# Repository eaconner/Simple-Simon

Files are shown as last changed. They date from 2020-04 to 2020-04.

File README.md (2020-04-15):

# Simple Simon Kit #

Simple Simon

Red then green...no, blue?...wait!...BUZZ! Remember the classic game of Simon?
Well, here is a build-your-own Simon kit that will sharpen your reaction time while teaching you basic soldering (a useful skill in its own right).

After you have successfully built a working Simon game, you will have a greater knowledge of through-hole soldering and the tools, techniques, and terminology required to populate your own PCB prototype. Additionally, the source code and design files are available, making this project a great entryway into microcontrollers and embedded programming. Game on!

## Parts List ##
|	Qty	|	Part				|	Description				|	Digikey Part #	|
|:-----:|---|---|---|
|	1	|	U1					|	Atmel ATtiny45			|	ATTINY45-20PU	|
|	4	|	R1, R2, R3, R4		|	470ohm 1/4w Resistor	|	CF14JT470RCT	|
|	1	|	D1					|	5mm Red LED				|	160-1678		|
|	1	|	D2					|	5mm Green LED			|	160-1677		|
|	1	|	D3					|	5mm Blue LED			|	160-1610		|
|	1	|	D4					|	5mm Yellow LED			|	160-1686		|
|	1	|	SG1					|	12mm Piezo Buzzer		|	102-3752		|
|	5	|	S1, S2, S3, S4, S5	|	Pushbutton				|	450-1644		|
|	1	|	BAT1				|	Battery Holder			|	BS-7			|
|	1	|	BAT1				|	CR2032 Battery			|	P189			|

## Instructions ##
1. Insert the ATtiny45 microcontroller into U1. Make sure the dot in the corner of the chip is aligned with the white silk screen dot on the board. Flip the board over, then solder into place.
2. Insert the (4) four resistors into R1, R2, R3, & R4 by bending the legs down. Flip the board over and solder into place.
3. Insert the (4) four LEDs into D1, D2, D3, & D4. Each LED has a short leg and a long leg. The long leg goes into the hole closest to the edge of the board. Also make sure it sits flush with the PCB. Then solder into place. **Note: You can check the color of the LED by touching the long leg to the "+" side of the CR2032 battery and the short leg to the "-" side.**
4. Insert the buzzer into SG1. Flip the board over and solder into place.
5. Insert the battery holder on the back of the board into BAT1. Flip the board over and solder into place.
6. Insert the battery into the holder.

## Gameplay ##

Press the "Start" button to begin. Memorize and repeat an increasing sequence of colors and tones. In higher levels the game goes faster. If you make a mistake, the correct LED blinks three times and game-over animation is played. If you have beaten the best score, your score is saved and the best-score animation is played.

- If the **red** button is held during when the start button is pressed, the best score is erased.
- If the **green** button is held during when the start button is pressed, starts a random sequence of lights and tones.
- If the **blue** button is held during when the start button is pressed, starts a new game at the highest achieved level.
- If the **yellow** button is held during when the start button is pressed, toggles the sound on or off.

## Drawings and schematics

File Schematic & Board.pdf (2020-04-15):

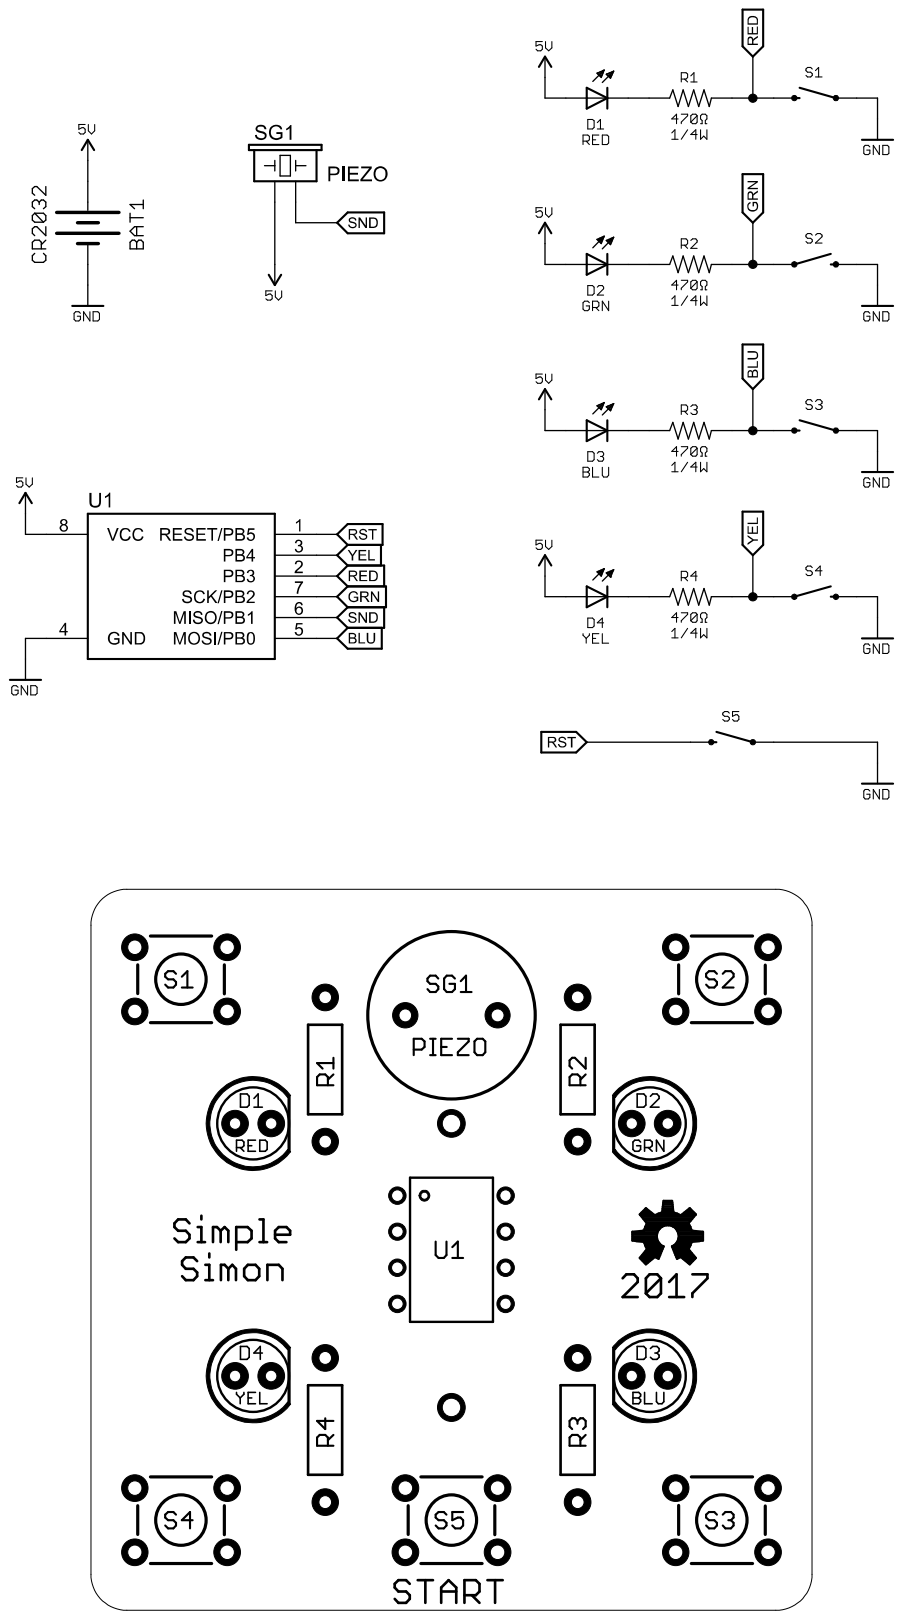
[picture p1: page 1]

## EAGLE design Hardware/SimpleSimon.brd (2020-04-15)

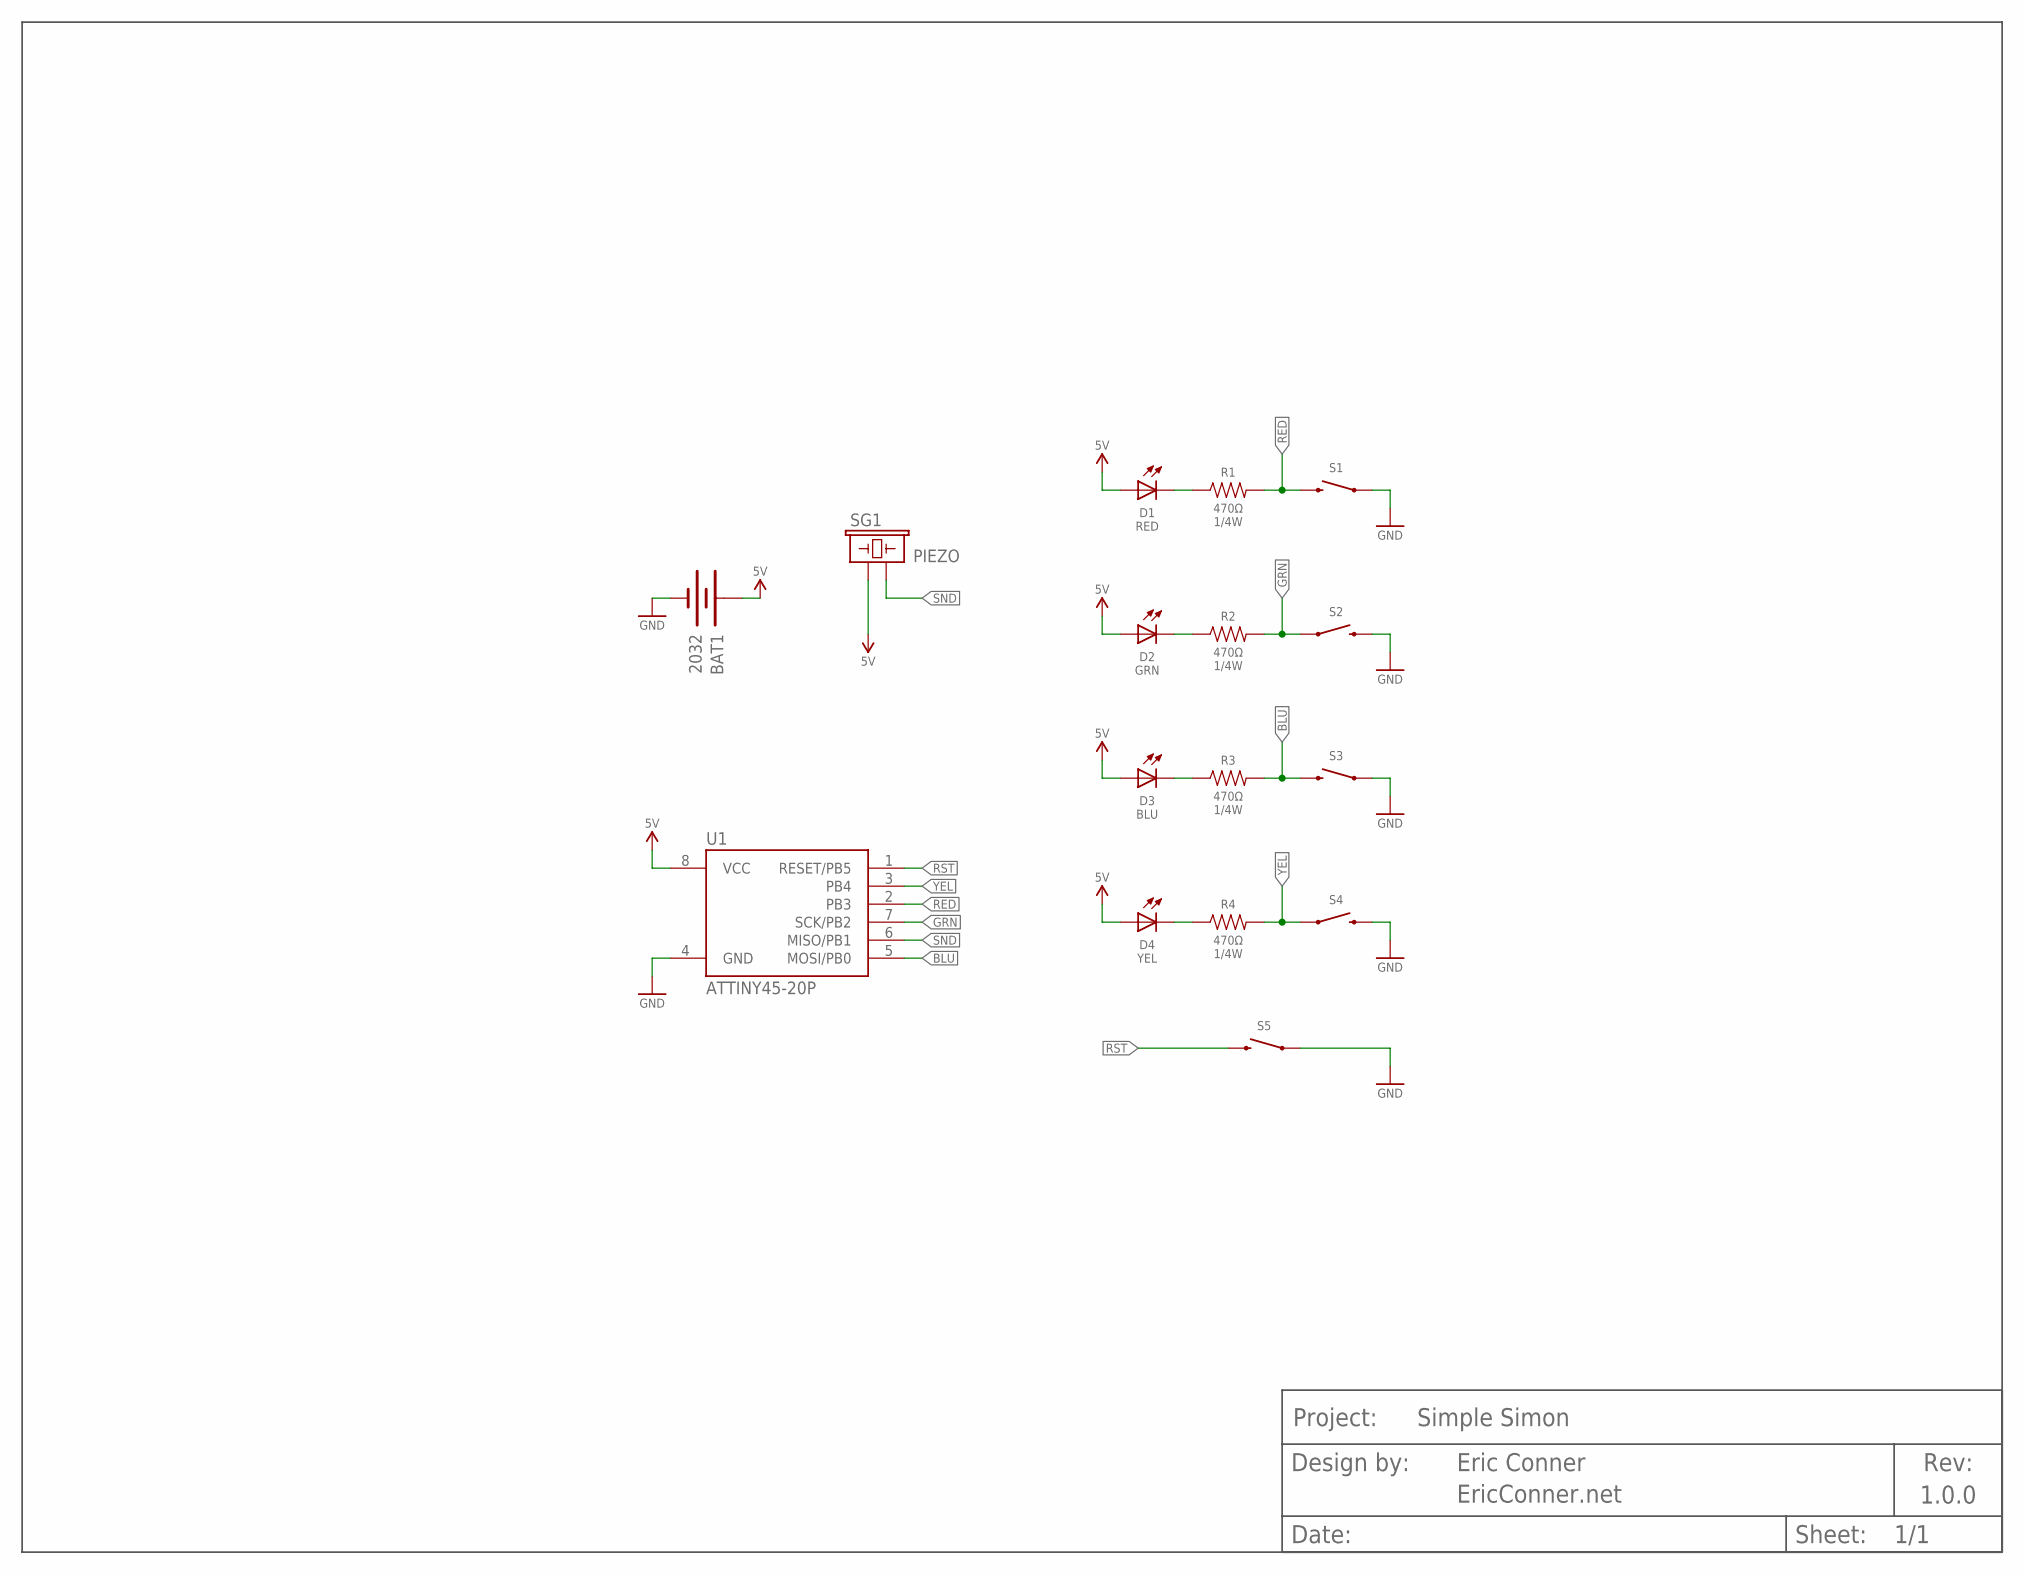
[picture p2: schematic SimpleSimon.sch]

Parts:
BAT1: 2032; BAT-2032; DIGIKEY BS-7-ND
BORDER1: BORDER_LETTER-MINIMAL; MINIMAL_LOGO
D1: RED; LED5MM; DIGIKEY 160-1678-ND
D2: GRN; LED5MM; DIGIKEY 160-1677-ND
D3: BLU; LED5MM; DIGIKEY 160-1610-ND
D4: YEL; LED5MM; DIGIKEY 160-1686-ND
R1, R2, R3, R4: 470Ω; 1/4R; DIGIKEY CF14JT470RCT-ND
S1, S2, S3, S4, S5: SWITCH-MOMENTARY-2PTH; TACTILE-PTH; DIGIKEY 450-1644-ND
SG1: PIEZO; BUZZER-12MM; DIGIKEY 102-3752-ND
U1: ATTINY45-20P; PDIP08_300MIL; DIGIKEY ATTINY45-20PU-ND

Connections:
BLU: R3.P$2 (2), S3.3 (2), U1.5 (MOSI/PB0)
GND: BAT1.-, S1.1, S2.3 (2), S3.1, S4.3 (2), S5.1, U1.4 (GND)
GRN: R2.P$2 (2), S2.1, U1.7 (SCK/PB2)
unnamed: D1.K (C), R1.P$1 (1)
unnamed: D2.K (C), R2.P$1 (1)
unnamed: D3.K (C), R3.P$1 (1)
unnamed: D4.K (C), R4.P$1 (1)
RED: R1.P$2 (2), S1.3 (2), U1.2 (PB3)
RST: S5.3 (2), U1.1 (RESET/PB5)
SND: SG1.- (2), U1.6 (MISO/PB1)
VCC: BAT1.+, D1.A, D2.A, D3.A, D4.A, SG1.+ (1), U1.8 (VCC)
YEL: R4.P$2 (2), S4.1, U1.3 (PB4)

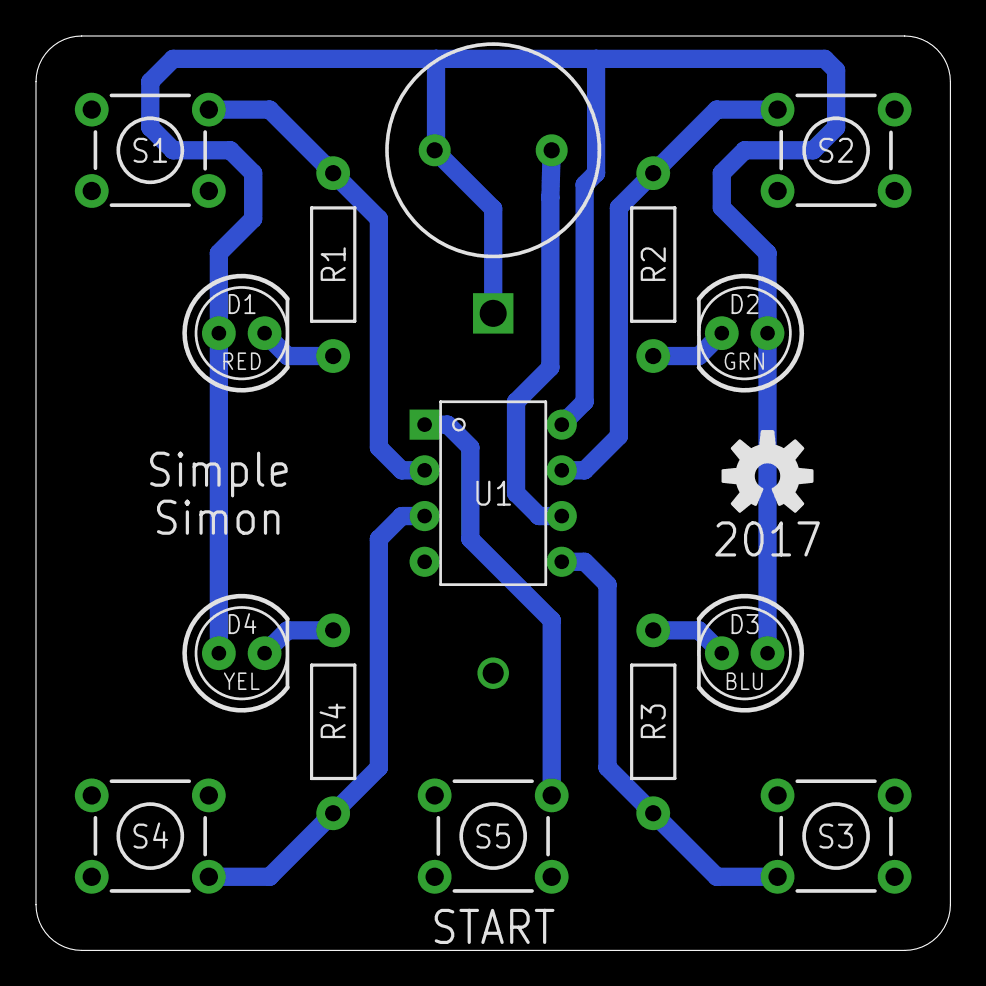
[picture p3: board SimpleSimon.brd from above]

Board: 2 copper layers, 50.8 x 50.8 mm, 18 parts (1 on the bottom side), 12 nets.

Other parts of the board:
U$1: OSHW-LOGO-M

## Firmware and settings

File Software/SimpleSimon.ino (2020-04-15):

/*
	Author: Eric Conner
	Project: Simple Simon
	Date: 01-09-2017
	File: SimpleSimon.ino
	Copyright (c) 2017, Eric Conner Apps. All right Reserved.
*/

#include <avr/wdt.h>
#include <avr/sleep.h>
#include <avr/interrupt.h>
#include <avr/eeprom.h>
#include <util/delay_basic.h>

const uint8_t buttons[4] = {
	0b00001010, 0b00000110, 0b00000011, 0b00010010
};

const uint8_t note[4] = {
	239, 179, 143, 119
};

uint8_t lastKey;
uint8_t lvl = 0;
uint8_t maxLvl;
uint16_t ctx;
uint16_t seed;
uint8_t sound;
volatile uint8_t nrot = 8;
volatile uint16_t time;

void setup() {
	DDRB = 0b00000000;
	PORTB = 0b00011101;
	
	ADCSRA |= (1 << ADEN); // enable ADC
	ADCSRA |= (1 << ADSC); // start the conversion on unconnected ADC0 (ADMUX = 0b00000000 by default)
	while(ADCSRA & (1 << ADSC)); // ADSC is cleared when the conversion finishes
	seed = ADCL; // set seed to lower ADC byte
	ADCSRA = 0b00000000; // turn off ADC

	if(MCUSR & _BV(WDRF)){ // If a reset was caused by the Watchdog Timer...
		MCUSR &= ~_BV(WDRF); // Clear the WDT reset flag
		WDTCR |= (_BV(WDCE) | _BV(WDE)); // Enable the WD Change Bit
		WDTCR = 0x00; // Disable the WDT
	}
	
	wdt_disable();
	WDTCR |= (_BV(WDCE) | _BV(WDE)); // Enable the WD Change Bit
	WDTCR = _BV(WDIE); // start watchdog timer with 16ms prescaler (interrupt mode)
	sei();
	
	while(nrot);
	
	TCCR0B = (1 << CS00); // Timer0 in normal mode (no prescaler)
	TCCR0A = (1 << COM0B1) | (0 << COM0B0) | (0 << WGM01) | (1 << WGM00); // set Timer0 to phase correct PWM
	
	maxLvl = ~eeprom_read_byte((uint8_t*) 0);
	sound = ~eeprom_read_byte((uint8_t*) 1);
	
	switch(PINB & 0b00011101) {
		case 0b00010101: // Red button is pressed during reset
			eeprom_write_byte((uint8_t*) 0, 255); // reset best score
			maxLvl = 0;
			break;
		case 0b00011001: // Green button is pressed during reset
			lvl = 255; // play random tones in an infinite loop
			break;
		case 0b00011100: // Blue button is pressed during reset
			lvl = maxLvl; // start from max level
			break;
		case 0b00001101: // Yellow button is pressed during reset
			if(sound) { // Toggle sound on/off
				sound = 0;
				eeprom_write_byte((uint8_t*) 1, ~sound);
			} else {
				sound = 1;
				eeprom_write_byte((uint8_t*) 1, ~sound);
			}
			break;
	}
}

ISR(WDT_vect) {
	time++; // increase each 16 ms
	if(nrot) { // random seed generation
		nrot--;
		seed = (seed << 1) ^ TCNT0;
	}
}

void sleepNow() {
	PORTB = 0b00000000; // disable all pull-up resistors
	cli(); // disable all interrupts
	WDTCR = 0; // turn off the Watchdog timer
	set_sleep_mode(SLEEP_MODE_PWR_DOWN);
	sleep_enable();
	sleep_cpu();
}

void resetCtx() {
	ctx = seed;
}

uint8_t random4() {
	ctx = 2053 * ctx + 13849;
	uint8_t temp = ctx ^ (ctx >> 8); // XOR two bytes
	temp ^= (temp >> 4); // XOR two nibbles
	return (temp ^ (temp >> 2)) & 0b00000011; // XOR two pairs of bits and return remainder after division by 4
}

void play(uint8_t i, uint16_t t = 45000) {
	PORTB = 0b00000000; // set all button pins low or disable pull-up resistors
	if(sound) {
		DDRB = buttons[i]; // set speaker and #i button pin as output
		OCR0A = note[i];
		OCR0B = note[i] >> 1;
		TCCR0B = (1 << WGM02) | (1 << CS01); // prescaler /8
		_delay_loop_2(t);
		TCCR0B = 0b00000000; // no clock source (Timer0 stopped)
	} else {
		DDRB = buttons[i] & 0b00011101;
		_delay_loop_2(t);
	}
	DDRB = 0b00000000;
	PORTB = 0b00011101;
}

void levelUp() {
	for(uint8_t i = 0; i < 4; i++) {
		play(i, 25000);
	}
}

void gameOver() {
	for(uint8_t i = 0; i < 4; i++) {
		play(3 - i, 25000);
	}
	
	if(lvl > maxLvl) {
		eeprom_write_byte((uint8_t*) 0, ~lvl); // write best score
		for(uint8_t i = 0; i < 3; i++) { // play best score melody
			levelUp();
		}
	}
	
	sleepNow();
}

void loop() {
	resetCtx();
	
	for(uint8_t cnt = 0; cnt <= lvl; cnt++) { // never ends if lvl == 255
		_delay_loop_2(4400 + 489088 / (8 + lvl));
		play(random4());
	}
	
	time = 0;
	lastKey = 5;
	resetCtx();
	
	for(uint8_t cnt = 0; cnt <= lvl; cnt++) {
		bool pressed = false;
		while(!pressed) {
			for(uint8_t i = 0; i < 4; i++) {
				if(!(PINB & buttons[i] & 0b00011101)) {
					if(time > 1 || i != lastKey) {
						play(i);
						pressed = true;
						uint8_t correct = random4();
						if(i != correct) {
							for(uint8_t j = 0; j < 3; j++) {
								_delay_loop_2(10000);
								play(correct, 20000);
							}
							_delay_loop_2(65536);
							gameOver();
						}
						time = 0;
						lastKey = i;
						break;
					}
					time = 0;
				}
				if(time > 1000) {
					gameOver();
				}
			}
		}
	}

	_delay_loop_2(65536);

	if(lvl < 254) {
		lvl++;
		levelUp(); // animation for completed level
		_delay_loop_2(45000);
	} else { // special animation for highest allowable (255th) level
		levelUp();
		gameOver(); // then turn off
	}
}

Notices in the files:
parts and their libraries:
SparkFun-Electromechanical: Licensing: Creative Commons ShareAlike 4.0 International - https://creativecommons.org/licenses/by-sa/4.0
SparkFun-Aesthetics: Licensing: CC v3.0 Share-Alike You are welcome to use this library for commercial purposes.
